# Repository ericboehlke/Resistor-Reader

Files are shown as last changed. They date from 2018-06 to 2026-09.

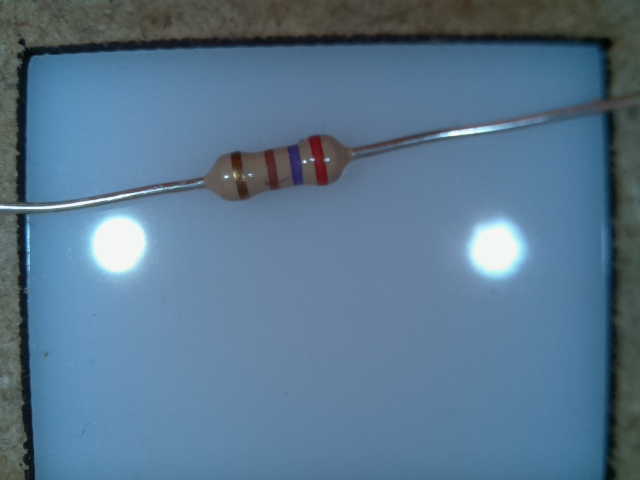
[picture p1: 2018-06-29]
resistor_pictures/0009.jpg

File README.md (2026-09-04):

# Resistor-Reader

Press a button, and a Raspberry Pi Zero photographs the 4-band resistor sitting
on its tray, decodes the colour code with OpenCV, and shows the resistance on a
14-segment display. Fixed LEDs keep the lighting consistent; a failure shows an
error code instead of a wrong answer.

Currently reads **121 of 128** sample images correctly (94.5%). Only tan-bodied
4-band resistors are in scope.

* [docs/ARCHITECTURE.md](docs/ARCHITECTURE.md) — how the pipeline works
* [docs/WORKFLOW.md](docs/WORKFLOW.md) — how to develop and tune it
* [docs/CODE_REVIEW_TODO.md](docs/CODE_REVIEW_TODO.md) — what still needs doing
* [hardware/WIRING.md](hardware/WIRING.md) — enclosure, GPIO wiring, and fasteners

## Development

Uses [uv](https://github.com/astral-sh/uv) for dependencies and
[flit](https://flit.pypa.io) as the build backend. Needs Python 3.11+.

```bash
uv sync            # install
uv run pytest      # run the tests
uvx ruff check .   # lint
uv build           # build a distribution
```

The CV pipeline runs anywhere. `main.py` needs the Pi's hardware (GPIO,
picamera2, I2C display), so on a dev machine drive the pipeline directly:

```bash
uv run python -c "
import numpy, PIL.Image
from resistor_reader.orchestrator import read_pipeline, load_config
r = read_pipeline(numpy.asarray(PIL.Image.open('resistor_pictures/0000.jpg')),
                  load_config('config.yaml'))
print(r.resistance, [c.value for c in r.colors])"
```

## Modes

`main.py` has three:

* **read** — the real one. Waits for the button, captures, runs the pipeline,
  displays the resistance or an error code.
* **gather** — prompts for a known resistance, captures, and appends the image
  and its value to the CSV. This built the test set.
* **camera** — captures to a numbered file on each press. Nothing else.

## Install on a Raspberry Pi Zero

`scripts/prep-sd-card.sh` builds the whole image on a fast machine through a
qemu-arm chroot, so the Pi never has to run `apt` or compile anything. It
installs the packages, clones this repo, builds the venv, enables I2C, installs
the systemd unit, and sets up a CDC-NCM USB gadget so the Pi answers at
`10.42.0.1` over the USB cable.

```bash
sudo ./scripts/prep-sd-card.sh          # see the header for env vars
```

Flash the resulting image, boot it, and the reader starts automatically:

```bash
ssh pi@10.42.0.1
systemctl status resistor-reader
journalctl -u resistor-reader -f
```

To run it by hand, stop the service first:

```bash
sudo systemctl stop resistor-reader
cd ~/Resistor-Reader && .venv/bin/python -m resistor_reader.main read
```

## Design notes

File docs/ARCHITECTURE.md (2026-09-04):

# Architecture

How the resistor reader works today. This describes the code as it is; work
still to be done lives in [CODE_REVIEW_TODO.md](CODE_REVIEW_TODO.md).

## The device

A Raspberry Pi Zero with a camera module looks down at a white acrylic tray
under fixed LEDs. Press the button, and it photographs the 4-band resistor on
the tray, decodes the colour code, and shows the resistance on a 14-segment
display. A failure shows an error code instead.

Only tan-bodied 4-band resistors are in scope.

## The pipeline

`orchestrator.read_pipeline(image, config) -> PipelineResult` runs five stages
in order and short-circuits on the first failure.

| Stage | Module | Produces | Fails with |
| --- | --- | --- | --- |
| Preprocess | `preprocess.py` | tray crop, white balanced | `E07` |
| ROI | `roi.py` | resistor body, rotated horizontal, + body mask | `E02` |
| Segmentation | `segment.py` | four band bounding boxes, + body texture | `E03` |
| Classification | `classify.py` | a score per colour per band | `E04` |
| Decode | `decode.py` | resistance, band order, confidence | `E04` |

### Preprocess

Crops to the tray interior (`processing.crop`, default `[64, 36, 480, 598]` for
a 640x480 capture — outside it is the MDF frame) and applies a gray-world white
balance. A frame the crop does not fit fails with `E07` rather than being
silently truncated.

### ROI

Masks the resistor against the white background by hue distance from the
border's median hue, erodes away the thin leads with a distance transform,
keeps the largest connected component, then rotates the body horizontal and
crops it. Returns the crop and the aligned body mask.

Getting the whole resistor into the mask consistently is still the weak point;
the next stage only needs enough of the bands to segment them, but the better
this stage does, the easier that is.

### Segmentation

Builds a one-dimensional "bandness" signal across the body from two cues:

* **colour** — LAB distance of each column from the resistor body colour,
  measured on a central horizontal strip and averaged over only the darkest
  rows, so specular blobs cannot drag it toward white;
* **texture** — the specular spread of each column, which is the only thing
  that makes a metallic gold band stand out from the beige body it is on.

Plain glare sparkles exactly as hard as a metallic band, so the texture cue is
gated on the *chroma of the highlight*: a metallic sparkle stays a saturated
gold, a reflection off the body washes out to near-white. The texture
contribution is capped so a gold band cannot tower over the others and drag the
detection threshold up with it.

Bands are then extracted as runs above a threshold. No single threshold works
for every resistor — a metallic band scores several times higher than a gray
band next to the body — so the code sweeps for a threshold yielding exactly four
runs, and when none does, keeps the runs it found and fills the rest by claiming
the strongest peaks among the leftover columns. Filling never subdivides a run
already found, which is what stops two boxes landing on the same band.

### Classification

Returns a *score for every colour* on every band rather than a hard label.
Alongside the LAB distance to each reference colour it adds a metallic term:
gold and silver carry their identity in their sparkle, which the matte median
that identifies every other colour deliberately throws away. Without that term
a gold band is indistinguishable from brown, which was the single largest
source of wrong readings.

### Decode

`decode_best` searches both band orders and the top few colour candidates per
band, keeps only sequences forming a legal resistor code, and returns the best
scoring one. Choosing the order is not a detail: a resistor is as likely to be
photographed tolerance-band-left as tolerance-band-right, and the colours are
the only cue to which end is which. The rules are published standards, not
anything learned from the sample images:

* the tolerance band is never black, orange, yellow or white (EIA-RS-279);
* the first significant digit is never black — no leading-zero resistors;
* real parts come from the E24 preferred-value series (IEC 60063), applied as a
  bonus rather than a filter so an unusual part still decodes;
* the result must land in a plausible range.

`resolve_value` in the same module is the pure part: four ordered colours in, a
resistance out, no knowledge of which end is which.

It also returns a **confidence** — the winning reading's score margin over the
best alternative *value*. `main.py` refuses a reading below
`decode.min_confidence` with `E06`, because a wrong answer is worse than an
error. The gate lives in `main.py`, not in `read_pipeline`, so the test suite
keeps measuring raw algorithm accuracy rather than accuracy-after-policy.

## Stage contract

Every stage takes an input dataclass (image + config, plus whatever the previous
stage produced) and returns an output dataclass inheriting `StageResult`:

```python
@dataclass(kw_only=True)
class StageResult:
    error: ErrorCodeEnum | None = None   # None means success
    error_msg: str = ""
    debug_overlay: np.ndarray | None = None
    _metadata: dict[str, Any] = field(default_factory=dict)

    @property
    def success(self) -> bool:
        return self.error is None
```

Two rules make this work:

1. **A stage names its own failure.** The orchestrator propagates `error`
   unchanged; it never re-derives a code from a stage's position in the
   pipeline.
2. **`_metadata` is diagnostics only** — timings, thresholds, debug image
   paths. Anything the next stage needs is a real typed field. That is why
   `SegmentationOutput.body_tex` and `ClassificationOutput.scores` are fields
   and not dictionary keys.

## Error codes

`models.ErrorCodeEnum` is the single source of truth. Names are three
characters so they fit the display.

| Code | Meaning | Raised by |
| --- | --- | --- |
| E01 | camera failure | `main.py` |
| E02 | no resistor found | `roi` |
| E03 | too many/few bands found | `segment`, `classify` |
| E04 | invalid band set | `classify`, `decode` |
| E05 | pipeline crashed | `main.py` |
| E06 | low confidence | `main.py` |
| E07 | bad input image | `preprocess` |

## Debug montage

With `runtime.debug.enabled`, the orchestrator stacks a vertical montage of
every stage's view. Stages hand back their overlay in `debug_overlay`, so
building it never reads back a JPEG the same process just wrote.

```text
+-----------------------------+
| Input                       |
+-----------------------------+
| Preprocessed                |
+-----------------------------+
| ROI Cropped                 |
+-----------------------------+
| Segmentation                |  band boxes
+-----------------------------+
| Classification              |  boxes labelled with the arg-max colour
+-----------------------------+
| Final Overlay               |  boxes + decoded colours + ohms, or the error
+-----------------------------+
```

On failure the final overlay shows what was known at that point: the cropped
image with the error if segmentation failed, red boxes if the bands could not
be classified, the error text in place of the ohms value if decoding failed.

## Performance

Target: under 1 s per capture, preferably under 0.33 s.

Measured on an x86 dev box with debug off, median over 20 images: **6.3 ms**
total (ROI 2.5, classification 1.5, segmentation 1.1, preprocess 0.9, decode
0.2). Per-stage timings are recorded in `_metadata["timings_ms"]` on every run,
so the same numbers can be read off the Pi.

**Not yet measured on the Pi Zero** — that is Phase D and the number that
actually matters.

## Accuracy

121/128 sample images (94.5%). Splitting by resistor value with
`RESISTOR_SPLIT` gives 95.3% on the tuning half and 93.8% on the holdout half,
so the thresholds are not badly overfit to the sample set.

The goal is ~95% on resistors that are present and legible, with errors rare and
wrong answers rarer.

## Deployment

`scripts/prep-sd-card.sh` builds the SD card image on a fast machine via a
qemu-arm chroot: installs the packages, clones the repo, builds the venv,
installs `scripts/resistor-reader.service`, and sets up a CDC-NCM USB gadget at
a static 10.42.0.1 so the Pi is reachable over USB.

The reader starts at boot via systemd and restarts on failure. Logs go to the
journal, which Log2Ram keeps in RAM; debug images are off by default and capped
by `runtime.debug.max_files` when enabled, because `logs/` is that same RAM
disk.

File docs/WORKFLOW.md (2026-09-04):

# Development Workflow

## Setup

```bash
uv sync          # dependencies
uv run pytest    # the whole suite
uvx ruff check . # lint (clean; keep it that way)
```

Everything runs on a dev machine except `main.py`, which imports `board`,
`RPi.GPIO` and `picamera2` and only works on the Pi. Exercise the pipeline with
`orchestrator.read_pipeline` or the test suite instead.

## The regression suite

`test_resistors` in `tests/test_orchestrator.py` runs every photo in
`resistor_pictures/` against the known values in `resistor_pictures/resistors.csv`
(gathered with `main.py gather`). It is the source of truth for accuracy — 121
of 128 as of this writing.

Each run writes `logs/<timestamp>/test_failures.md`: a table of every failure
with the stage that failed, the error, the decoded colours, and a path to the
most useful debug image. Images that pass are run once with debug off; only
failures are re-run with debug on, so a clean run stays fast and does not fill
`logs/`.

The report is one file per run, not a running log across runs — use git if you
want history.

### Honest accuracy numbers

The thresholds were tuned against these photos, so a pass rate over all of them
flatters itself. `RESISTOR_SPLIT` cuts the set in half **by resistor value**
(every value was photographed twice, so splitting by filename would leak one
photo of a pair into the other half):

```bash
RESISTOR_SPLIT=tune    uv run pytest    # tune against this half
RESISTOR_SPLIT=holdout uv run pytest    # then read the honest number here
```

Unset runs everything. Currently 95.3% tune / 93.8% holdout.

## Interactive tuning

`scripts/live_trackbar.py` reruns the whole pipeline on one image as you drag
sliders, showing the debug montage live. It calls the same `read_pipeline` the
appliance does, so what you tune is what runs.

```bash
uv run python scripts/live_trackbar.py \
  --image resistor_pictures/0044.jpg --debug --save-config tuned.yaml
```

Keys: `s` saves the current values to `--save-config`, `r` resets to the file's
values, `q` or Escape quits.

The sliders are integers, so `seg_max_w` and `seg_tex_w` carry their real value
scaled by 100. Adding a slider means adding a row to `TRACKBARS` and, for a
fractional parameter, to `_PERCENT_TRACKBARS`.

## Configuration

One file, `config.yaml`, holds every tunable, and it is what the appliance runs.
Tests load it and force the debug switches in code — there is deliberately no
second copy of the tunables under `tests/`, because a second copy only drifts.

Debug is **off** by default: `logs/` on the appliance is a Log2Ram RAM disk, and
each enabled stage writes a JPEG per button press. `runtime.debug.max_files`
caps the directory when it is on.

Note that stage defaults currently live in two places — `config.yaml` and the
`_*_cfg()` fallbacks in each stage — so a key typo silently falls back to the
code default. See [CODE_REVIEW_TODO.md](CODE_REVIEW_TODO.md).

## Conventions

* Every stage takes an input dataclass and returns an output dataclass; see the
  stage contract in [ARCHITECTURE.md](ARCHITECTURE.md).
* A stage names its own failure with an `ErrorCodeEnum`. Do not add a code
  without adding it to the table in ARCHITECTURE.md.
* `_metadata` is for diagnostics. If the next stage needs it, it is a field.
* Performance matters: the target is under a third of a second on a Pi Zero.
  Vectorize with NumPy/OpenCV; no Python loops over pixels, no ML frameworks.

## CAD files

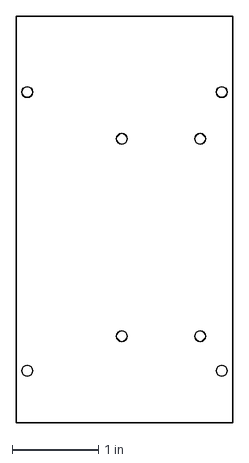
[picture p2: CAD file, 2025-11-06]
hardware/dxfs/back.dxf
2.50 x 4.70 in

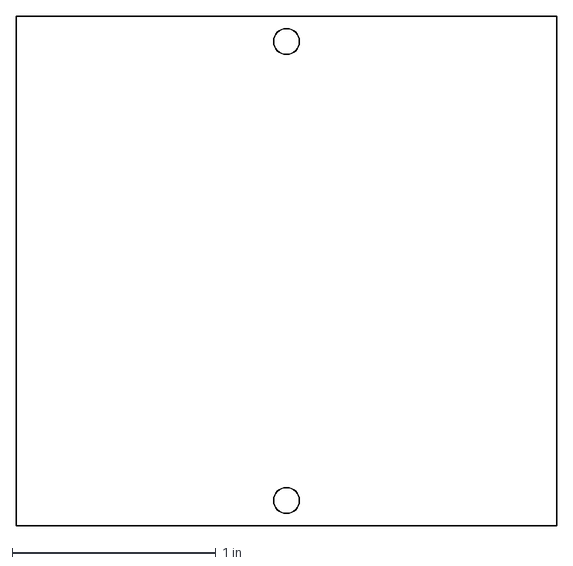
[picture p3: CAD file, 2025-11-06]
hardware/dxfs/bottom.dxf
2.65 x 2.50 in

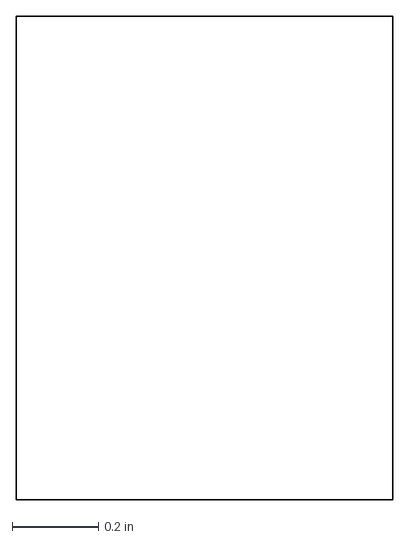
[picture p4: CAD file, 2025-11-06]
hardware/dxfs/background.dxf
0.875 x 1.12 in

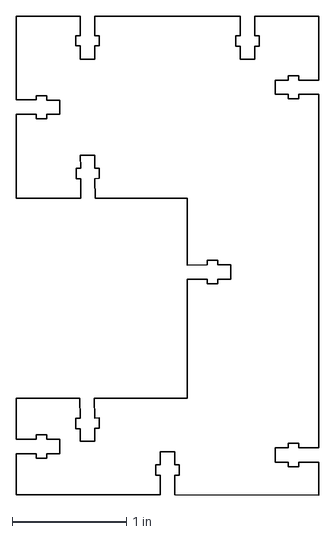
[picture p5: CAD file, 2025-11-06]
hardware/dxfs/right_side.dxf
2.65 x 4.20 in

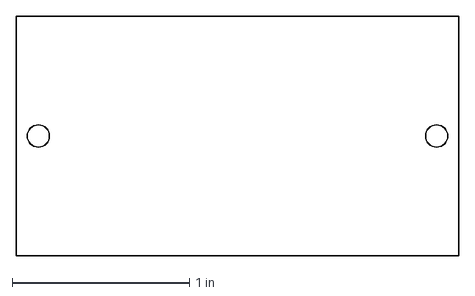
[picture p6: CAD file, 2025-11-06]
hardware/dxfs/bottom_front.dxf
2.50 x 1.35 in

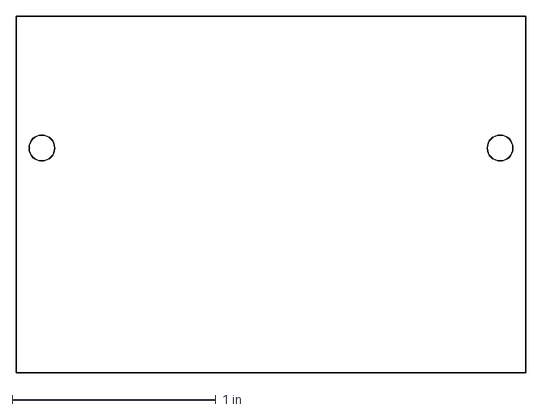
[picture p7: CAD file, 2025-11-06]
hardware/dxfs/backstop.dxf
2.50 x 1.75 in

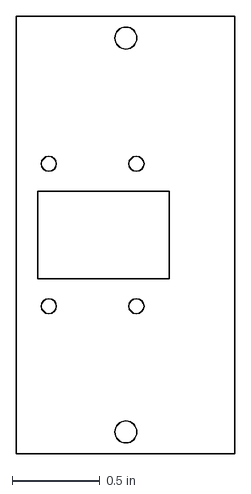
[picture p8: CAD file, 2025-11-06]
hardware/dxfs/camera_mount.dxf
1.25 x 2.50 in

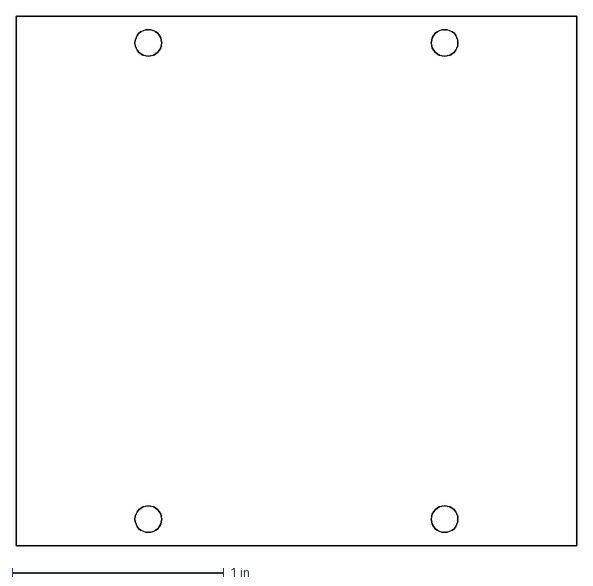
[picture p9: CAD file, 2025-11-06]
hardware/dxfs/top.dxf
2.65 x 2.50 in

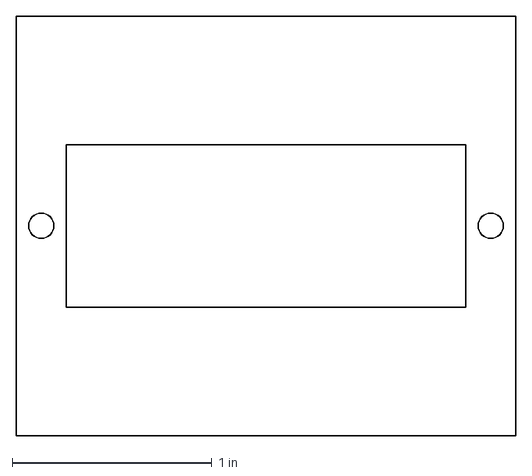
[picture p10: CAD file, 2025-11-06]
hardware/dxfs/top_front.dxf
2.50 x 2.10 in

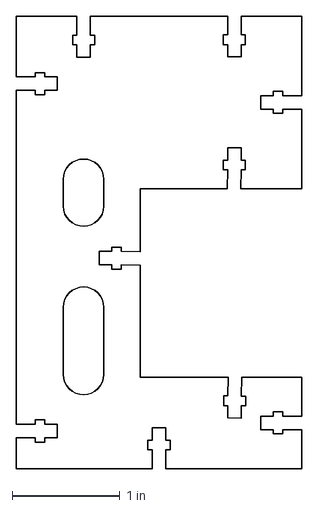
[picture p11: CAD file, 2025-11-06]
hardware/dxfs/left_side.dxf
2.65 x 4.20 in

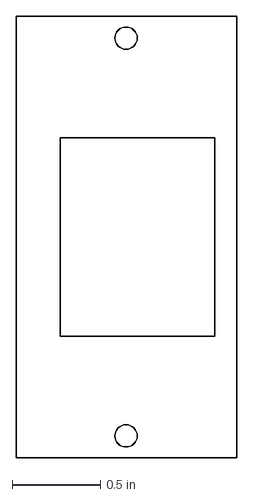
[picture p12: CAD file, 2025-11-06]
hardware/dxfs/bed.dxf
1.25 x 2.50 in

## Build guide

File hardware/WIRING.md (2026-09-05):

# Wiring & mechanical hardware

The enclosure, GPIO wiring, and fasteners for the Pi Zero appliance. This
describes the physical unit; see [docs/ARCHITECTURE.md](../docs/ARCHITECTURE.md)
for the software.

## Parts list

### Mechanical (enclosure)

MDF panels, cut from the DXFs in [`dxfs/`](dxfs): `back`, `background`,
`backstop`, `bed`, `bottom`, `bottom_front`, `camera_mount`, `left_side`,
`right_side`, `top`, `top_front`. Panel stock is nominal 1/4 in (6 mm) MDF.

| Part | Spec | Qty |
| --- | --- | --- |
| Panel-to-panel screw | M3 x 16 mm button head cap screw | 20 | 
| Panel-to-panel nuts | M3 nuts | 20 | 
| Pi standoff | M2.5 x 12 mm nylon standoff, female-female | 4 | 
| Pi standoff screw | M2.5 x 8 mm nylon screw | 8 | 
| Camera mount screw | M2 x 14 mm button head cap screw | 4 | 
| Camera mount nuts | M2 nuts | 4 | 

### Electronic

| Part | Spec |
| --- | --- |
| SBC | Raspberry Pi Zero |
| Camera | Pi Camera Module, `ov5647` sensor, CSI ribbon |
| Display | [Adafruit HT16K33 backpack, 4-digit 14-segment](https://www.adafruit.com/product/1911) |
| Button | Momentary pushbutton — see [Button wiring](#button-wiring) |
| Tray LEDs | 2x white LEDs — see [LED driver](#led-driver) |
| LED resistors | 2x 100Ω, 1/4W, one per LED branch |
| LED driver transistor | 2N2222 NPN, low-side switch: emitter to ground, collector to the LED branches' common return |
| LED base resistor | 1kΩ |
| Reverse-polarity protection | P-channel MOSFET, high-side reverse-polarity stage on the incoming 5V |
| Bulk capacitance | ~2200µF low-ESR electrolytic + 100nF ceramic, on the 5V rail near the Pi's power pin |
| DC-input-sense divider | 10kΩ / 15kΩ resistor divider, tapped off the raw incoming 5V (before reverse-polarity protection) into a spare GPIO |
| Power input jack | 5.5x2.1mm panel-mount DC barrel jack, center-positive — mounts in a hole in the case's back panel |
| Board power connector | 1x2 right-angle male header (board side) + matching Dupont female housing (harness side) — see [Connectors](#connectors)|
| LED connector | 1x4 right-angle male header (board side) + matching Dupont female housing (harness side) — see [Connectors](#connectors) |
| Display connector | 1x5 right-angle male header (board side) + matching Dupont female housing (harness side) — see [Connectors](#connectors) |
| Button connector | 1x2 right-angle male header (board side) + matching Dupont female housing (harness side) — see [Connectors](#connectors) |

## Power input

Power comes in over a panel-mount DC barrel jack, 5V only — no USB-C, no
negotiation of any kind, no buck/boost stage, since the input is already at
the 5V the Pi and LEDs want. This is deliberately the simplest option: a
barrel jack is just two conductors (center + shield), with no connector-side
electronics or breakout board to select and mate.

- **Connector:** a 5.5x2.1mm panel-mount DC barrel jack, center-positive
  (the near-universal convention for 5V wall adapters), mounted in a hole in
  the case's back panel. Two wires run from it to a 2-pin header on the
  board.
- **Current headroom:** unlike USB-C, there's no negotiation step at all —
  whatever the wall adapter is rated for is what's available, no resistor
  values or connector logic involved. **Minimum recommended supply: 5V/2A**,
  given the worst-case simultaneous load of camera capture + both LEDs +
  display digits lit at once.
- **Reverse-polarity protection:** a P-channel MOSFET stage rather than a
  series diode — a diode's ~0.3-0.4V drop would eat too far into the Pi's
  already-thin under-voltage margin on a bare 5V-in design with no
  regulator stage to make it up. This matters more than it would with
  USB-C: a barrel jack has no keying or polarity enforcement at all, and
  center-negative 5V adapters do exist, so a miswired or wrong adapter is a
  real (not just theoretical) risk here.
- **Bulk capacitance** on the 5V rail near the Pi's power pin does two
  jobs, which is why it's sized above a "just for ripple" value:
  1. Smooths the short (sub-second) current spike from camera + LEDs +
     display all drawing at once — the moment a reading is actually taken.
  2. Bridges the Pi through a clean shutdown once power loss is detected
     (see [Soft shutdown](#soft-shutdown-on-power-loss) below) for a few
     hundred ms under typical debugging-session load. This is explicitly
     **not** sized to survive a worst-case fully-loaded unplug — a
     guarantee like that would need a supercap + boost UPS stage, which
     was considered and deliberately skipped in favor of this simpler cap.
  Final value should be checked against measured peak current once built,
  not just typical datasheet numbers.
- The protected, buffered 5V feeds the Pi's 5V pin directly (powered via
  the GPIO header rather than the Pi's own micro-USB port) and the LED
  driver branch.
- If `vcgencmd get_throttled` or dmesg under-voltage warnings show up
  during real-load testing anyway, the next step is a shorter/thicker
  cable/wire run or an added boost stage — not built in preemptively.

### Soft shutdown on power loss

To reduce the risk of SD card corruption if the barrel jack is unplugged —
most relevant when the root filesystem's read-only protection is turned off
for debugging — a spare GPIO senses the raw incoming 5V (before the
reverse-polarity stage) through the 10kΩ/15kΩ divider above. That raw input
collapses essentially instantly on unplug, well before the downstream bulk
capacitor sags, so the Pi gets an early edge to react to while it's still
running on stored charge. A small watcher (same gpiozero pattern already
used for the button in `resistor_reader/main.py`) should trigger a clean
`shutdown -h now` on that falling edge. **This watcher script/systemd unit
is a software follow-up, not delivered as part of this hardware plan** —
see the checklist below.

## GPIO pinout

The Pi's 40-pin header is 20 rows of 2 pins, running away from the SD card
slot. "Row *N*" below counts rows from the SD-card end (row 1 = pins 1/2).
Within a row, **inside** = the odd-numbered pin, **outside** = the
even-numbered pin.

| Row (from SD card) | Inside pin | Outside pin | Function |
| --- | --- | --- | --- |
| 1 | Pin 1 — **3.3V** | Pin 2 — **5V** | Inside: display VCC/Vi2c + button. Outside: 5V rail (LED driver supply + Pi power) |
| 2 | Pin 3 — **GPIO2 (SDA1)** | Pin 4 — 5V | Inside: display SDA |
| 3 | Pin 5 — **GPIO3 (SCL1)** | Pin 6 — **GND** | Inside: display SCL. Outside: ground return |
| 6 | Pin 11 — **GPIO17** | Pin 12 — GPIO18 (unused) | Button signal, active-high, internal pull-down — see [Button wiring](#button-wiring) |
| 7 | Pin 13 — **GPIO27** | Pin 14 — GND | LED driver control, via transistor base resistor |
| 8 | Pin 15 — **GPIO22** | Pin 16 — GND (unused) | DC-input-sense input for soft shutdown — new, not yet read by any software |

Matches `main.py`'s existing defaults (`button_pin=17`, `leds_pin=27`,
`resistor_reader/main.py:305-306`) and I2C1 defaults (`board.I2C()` in
`setup_display()`). GPIO22 is newly assigned for VBUS sensing and isn't
referenced by any code yet.

## Button wiring

The button sits between 3.3V and `GPIO17`, with no separate ground leg.
`setup_gpio()` in `main.py` configures `Button(pin, pull_up=False, ...)`,
which enables GPIO17's internal pull-down: the pin idles LOW and reads HIGH
when the button ties it to 3.3V on a press. This is the deliberate design —
it needs no external pull resistor and no code changes.

## LED driver

The two tray LEDs are white, which puts their forward voltage
around 3.0-3.2V @ 20mA typical — too high for two in series on a 5V rail
(that would need ~6.0-6.4V combined). They're wired as **two parallel
branches**, each with its own 100Ω resistor, sharing a single 2N2222
low-side switch:

- Rail: 5V. Transistor: `Vce(sat)` ≈ 0.2V.
- Per branch: `Vresistor = 5V − Vf − Vce(sat) ≈ 5 − 3.0..3.2 − 0.2 ≈ 1.6-1.8V`
- `I = Vresistor / 100Ω ≈ 16-18mA` per LED — safely under a typical 20mA
  max, with the resistor dissipating ~30mW (well under a 1/4W part's rating).
- Each LED gets its **own** resistor rather than sharing one across both
  parallel LEDs, so a slight Vf mismatch between the two doesn't cause one
  LED to hog current from the other.
- Both resistors live **on the main board**; only the bare LEDs are remote
  (out in the tray). Each LED's anode (post-resistor) and cathode return
  are carried as two independent conductors over the 1x4 harness — see
  [Connectors](#connectors) — with the two cathode returns joining at the
  transistor's collector back on the board.
- Base: `GPIO27` through a 1kΩ resistor, `Ib ≈ 2.6mA`. Total collector
  current for both branches is ~34mA, far below what a 2N2222 needs to
  saturate (min hFE ~100 implies saturation well under 3.4mA of base
  current) — deep saturation is guaranteed with plenty of margin.
- The LED pin is driven purely on/off in software (`LED`, not `PWMLED`, in
  `resistor_reader/main.py`) — no PWM dimming to account for in the driver
  design.

## Circuit

```mermaid
graph LR
    subgraph PWR["Power input"]
        JACK["5.5x2.1mm barrel jack (panel mount)"]
        SENSE["10k/15k divider"]
        PROT["P-MOSFET reverse-polarity protection"]
        CAP["Bulk cap: 2200uF + 100nF"]
    end

    subgraph Pi["Pi Zero 40-pin header"]
        P1["Pin 1 — 3.3V"]
        P2["Pin 2 — 5V"]
        P3["Pin 3 — GPIO2 SDA1"]
        P5["Pin 5 — GPIO3 SCL1"]
        P6["Pin 6 — GND"]
        P11["Pin 11 — GPIO17"]
        P13["Pin 13 — GPIO27"]
        P15["Pin 15 — GPIO22"]
    end

    JACK -->|raw 5V| SENSE
    SENSE -->|sensed level| P15
    JACK -->|raw 5V| PROT
    PROT --> CAP
    CAP --> P2

    P1 --> DCONN["1x5 right-angle header"]
    P3 -->|SDA| DCONN
    P5 -->|SCL| DCONN
    P6 --> GND["Ground bus"]
    DCONN --> DISP["Display: VCC, Vi2c, GND, SDA, SCL"]

    P1 --> BCONN["1x2 right-angle header"]
    P11 ---|GPIO17, internal pull-down| BCONN
    BCONN --> BTN["Button (not illuminated)"]

    P13 --> BASE["1k ohm base resistor"]
    CAP --> Q1["2N2222 (collector)"]
    BASE --> Q1
    GND -->|emitter| Q1
    Q1 --> R1["100 ohm"] --> LCONN["1x4 right-angle header"]
    Q1 --> R2["100 ohm"] --> LCONN
    LCONN --> LED1["LED 1"] --> GND
    LCONN --> LED2["LED 2"] --> GND

    style DCONN fill:#3b82f6,color:#fff
    style CAP fill:#ef4444,color:#fff
    style GND fill:#111,color:#fff
    style BASE fill:#eab308,color:#000
    style PROT fill:#eab308,color:#000
```

## Connectors

Board-side headers are **right-angle**, not straight — the case's internal
clearance doesn't have room for a straight header plus a Dupont housing
stacked on top. Each mates with a Dupont female housing crimped onto the
corresponding harness.

| Connector | Pin 1 | Pin 2 | Pin 3 | Pin 4 | Pin 5 |
| --- | --- | --- | --- | --- | --- |
| LED (1x4) | LED1 anode (post-R1) | LED1 cathode return | LED2 anode (post-R2) | LED2 cathode return | — |
| Display (1x5) | VCC (3.3V) | Vi2c (3.3V, bridged to VCC on-board) | GND | SDA | SCL |
| Button (1x2) | 3.3V | GPIO17 | — | — | — |
| Power (1x2) | 5V | GND | — | — | — |

## Build checklist

Items to confirm as the build comes together:

1. **Confirm actual LED `Vf`** once the LEDs are in hand (measure or check
   the datasheet) — the 100Ω resistor value above assumes 3.0-3.2V; recompute
   if the real part differs meaningfully.
2. **Breadboard-test the power section** (barrel jack → reverse protection
   → bulk cap → Pi) before committing it to the enclosure.
3. **Check for under-voltage warnings** (`vcgencmd get_throttled`, dmesg)
   under real combined load — camera capture + LEDs + display active at
   once — with the actual wall adapter you intend to use.
4. **Confirm the barrel jack's panel-mount hardware fits** the case's back
   panel thickness, and double-check the wall adapter you use is
   center-positive before plugging it in.
   confirm they seat properly once the 5 mm standoffs are actually swapped in.
5. **Write the soft-shutdown watcher** (spare GPIO22 read via gpiozero,
   triggering a clean `shutdown -h now` on DC input loss) as a follow-up
   software task — not part of this hardware plan.
6. **Confirm the right-angle headers' mounted orientation clears the case**
   once the board is in hand — check that the LED (1x4), display (1x5), and
   button (1x2) Dupont housings can actually be seated with the board in
   its final mounted position.

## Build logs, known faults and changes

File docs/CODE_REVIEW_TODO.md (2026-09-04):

# Open work

What is left after the September 2026 cleanup. The review that produced this
list is in the git history; everything below is still open.

Current state: **121/128** sample images (94.5%; 95.3% tune / 93.8% holdout),
**6.3 ms** per image on an x86 dev box, `ruff check .` clean, 52 tests passing
plus `test_resistors` failing at the 7 images below.

---

## The seven failures

Ranked by how wrong they are. `logs/<run>/test_failures.md` links a debug
montage for each after any test run.

| Image | Expected | Read as | Confidence | Note |
| --- | --- | --- | --- | --- |
| 0110 | 1 M | 88 | 8.10 | worst miss; confident and wrong |
| 0067 | 22 k | 1.2 k | 0.22 | caught by the E06 gate |
| 0064 | 33 k | 43 k | 0.53 | caught by the E06 gate |
| 0044 | 3.9 k | 390 | 5.42 | multiplier band misread |
| 0127 | 2.2 | 220 | 3.95 | multiplier band misread |
| 0123 | 5.1 | 510 | 4.32 | multiplier band misread |
| 0126 | 5.1 | 5.0 | 3.33 | brown/black on the second digit |

- [ ] Four of the seven are **multiplier-band errors off by exactly 100x**
      (0044, 0127, 0123), or a gold/black multiplier confusion (0126). That is
      a pattern, not seven separate bugs — a metallic-vs-dark multiplier is the
      thing to look at first.
- [ ] 0110 is the only high-confidence miss and the only one the E06 gate
      cannot catch. Worth understanding on its own.

## Accuracy and calibration

- [ ] Take **50 more photos** with `main.py gather`. The current 128 are the
      set every threshold was tuned against; the holdout split says the tuning
      generalizes, but 64 held-out images is a thin basis for a 95% claim.
- [ ] Re-derive `decode.min_confidence` once there is more data. It is 1.0 now,
      measured on 128 images where only three fall below it — a threshold set
      from three data points.

## Pi Zero (Phase D)

- [ ] **Measure the pipeline on the actual Pi Zero.** Nothing here has ever
      been timed on target hardware. The budget is 1 s, ideally 0.33 s;
      per-stage timings are already recorded in `_metadata["timings_ms"]`, so
      this is a matter of reading them off a real run.
- [ ] Confirm the systemd unit works end to end on a fresh image: does it start
      on boot, does the button work, does the display come up, does it recover
      after a crash.

## Architecture

- [ ] **Stage defaults live in two places.** Every tunable is declared in
      `config.yaml` *and* in the `_*_cfg()` fallback in its stage, and a third
      time as the default column in `live_trackbar.TRACKBARS`. A typo'd YAML
      key silently falls back to the code default with no warning. Replace the
      `dict` config with typed dataclasses (`SegmentationConfig`,
      `ClassificationConfig`, `DecodeConfig`, `RuntimeConfig`) loaded once by
      `load_config`, rejecting unknown keys, and generate the trackbar list
      from their fields.
- [ ] `SegmentationOutput.bounding_boxes` always spans the full crop height
      (`(x0, 0, x1, h)`), so two of the four coordinates carry no information.
      Either make them mean something or make the type a column range.
- [ ] `main.py` uses bare `print()`. That works — the systemd unit sends stdout
      to the journal — but a real logger would let the appliance run quieter
      than the tuning session. Low priority.
- [ ] `tests/_best_debug_path` has three near-identical branches that differ
      only in ordering. Collapse.

## Deployment (Phase E)

- [ ] `docs/STEPS.md` planned a **pi-gen fork**. `scripts/prep-sd-card.sh`
      solved the same problem differently — staging a Raspbian Lite image on a
      loop device through a qemu-arm chroot — and is what actually works today.
      Decision: no pi-gen fork; delete the idea rather than carry it. Recorded
      here because the plan is otherwise only in the deleted file's history.
- [ ] Verify Log2Ram is actually configured on the built image. The debug-image
      cap and the journal both assume it.

---

## Done in this pass

For anyone reading the diff: unified the error code space (E01-E07, one owner
per code) and made stages report their own typed error; promoted `body_tex` and
the classifier `scores` matrix from the debug-only `_metadata` dict to real
fields; merged `resolve.py` into `decode.py`; rebuilt the orchestrator around a
run context, removing five copies of the result construction and the round-trip
that re-read stage overlays back off disk as JPEGs; split the 692-line
`bands.py` into `segment.py`/`classify.py`/`imageops.py`; moved the preprocess
crop and every ROI constant into config; made preprocess reject a frame it
cannot crop (E07) instead of silently truncating; turned debug off by default
and capped the debug directory; deleted the duplicate `tests/test.yaml`; wired
up the long-ignored decode confidence as an E06 gate; added
`scripts/resistor-reader.service`; fixed the `live_trackbar` slider that opened
the tool at 1/100th of the configured texture weight; deleted `read_resistor`,
`PipelineInput`, the unrunnable matplotlib plot path, nine unused test fixtures
and four stale documents; and brought `ruff` from 38 findings to zero and the
test count from 18 to 52.

Accuracy was 121/128 before and after — none of it was an algorithm change.

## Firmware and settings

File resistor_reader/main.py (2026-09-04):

"""Appliance entry point: button, camera, pipeline, segment display."""

from __future__ import annotations

import argparse
import csv
import time
import traceback
from dataclasses import dataclass, field
from pathlib import Path
from typing import Any

import board
from adafruit_ht16k33 import segments
from gpiozero import LED, Button
from picamera2 import Picamera2

from resistor_reader import orchestrator
from resistor_reader.display import resistance_str, show_error, show_message
from resistor_reader.models import ErrorCodeEnum


@dataclass
class Config:
    button_pin: int
    leds_pin: int
    resolution: tuple[int, int]
    awb_gains: tuple[float, float]
    save_dir: Path = Path("resistor_pictures")
    csv_path: Path = Path("resistor_pictures/resistors.csv")
    start_number: int = 0
    # Fixed exposure for the (unchanging) tray lighting. ``None`` means measure
    # it once at startup; see ``setup_camera``.
    exposure_time: int | None = None
    analogue_gain: float = 1.0
    # Loaded once at startup rather than re-read from disk on every capture.
    pipeline_config: dict[str, Any] = field(default_factory=dict)
    image_number: int = 0

    @property
    def min_confidence(self) -> float:
        """Score margin below which a reading is refused as ``E06``.

        Zero (the default) accepts every reading the decoder considers legal.
        """
        decode_cfg = self.pipeline_config.get("decode", {}) or {}
        return float(decode_cfg.get("min_confidence", 0.0))


def ensure_paths(config: Config):
    config.save_dir.mkdir(parents=True, exist_ok=True)
    if not config.csv_path.exists():
        with open(config.csv_path, "a", newline="") as f:
            writer = csv.writer(
                f, delimiter=",", quotechar="|", quoting=csv.QUOTE_MINIMAL
            )
            writer.writerow(["number", "resistance"])


def setup_gpio(config: Config) -> tuple[Button, LED]:
    # The switch ties the GPIO pin to 3.3V (not GND) when pressed -- see
    # hardware/WIRING.md -- so pull_up=False: gpiozero enables the internal
    # pull-down and reports the button pressed when the pin reads HIGH.
    # gpiozero picks the lgpio backend on this Pi (RPi.GPIO's edge detection
    # is broken on its kernel -- see wait_for_press's old docstring in git
    # history -- but lgpio talks to the modern gpiochip interface directly,
    # so edge waits work).
    button = Button(config.button_pin, pull_up=False, bounce_time=0.03)
    leds = LED(config.leds_pin)
    return button, leds


def setup_display():
    display = segments.Seg14x4(board.I2C())
    display.brightness = 0.5
    display.fill(0)
    return display


def _converge_exposure(
    cam, *, min_frames: int = 4, max_frames: int = 40, tol: float = 0.03
):
    """Step through frames until auto-exposure settles, and return the
    ``(ExposureTime microseconds, AnalogueGain)`` to lock in.

    With the LEDs on and steady, the AEC/AGC parks within a couple of frames
    and stays put; the hunting only happens when it meters a dark frame after
    the LEDs switch off between reads, which is exactly what locking prevents.
    ``capture_metadata`` blocks for the next frame, so the loop advances one
    frame per iteration.
    """
    prev = None
    exposure = gain = None
    for i in range(max_frames):
        metadata = cam.capture_metadata()
        exposure = metadata.get("ExposureTime")
        gain = metadata.get("AnalogueGain")
        if exposure is None or gain is None:
            break
        if i + 1 >= min_frames and prev and abs(exposure - prev) <= tol * prev:
            break
        prev = exposure
    if not exposure or not gain:
        raise RuntimeError("camera gave no exposure metadata to calibrate from")
    return int(exposure), float(gain)


def setup_camera(config: Config, leds: LED):
    cam = Picamera2()
    config_obj = cam.create_still_configuration(main={"size": config.resolution})
    cam.configure(config_obj)
    cam.start()

    # Manual white balance: the tray lighting is fixed, so a hunting AWB only
    # adds colour drift between reads.
    cam.set_controls({"AwbEnable": False, "ColourGains": config.awb_gains})

    # Lock exposure too. Left on auto, the AGC hunts to its ceiling after the
    # first frame and blows every later capture out -- red reads as orange,
    # brown as gold, or the resistor is lost against the background. The
    # lighting never changes, so one measurement under the LEDs holds for the
    # whole session.
    if config.exposure_time is not None:
        exposure, gain = config.exposure_time, config.analogue_gain
    else:
        leds.on()
        try:
            exposure, gain = _converge_exposure(cam)
        finally:
            leds.off()
        print(f"Calibrated exposure: {exposure} us at gain {gain:.2f}")
    cam.set_controls(
        {"AeEnable": False, "ExposureTime": exposure, "AnalogueGain": gain}
    )
    return cam


def gather_mode(picam2, display, config: Config, button: Button, leds: LED):
    """Gather mode:
    Prompt for resistance, take picture, save image and resistance in CSV.
    """
    show_message(display, "GATH")
    ensure_paths(config)
    resistance = input("resistance: ").strip()
    try:
        float(resistance)
    except ValueError:
        print("Invalid resistance value, please enter a number.")
        return
    show_message(display, resistance_str(float(resistance)))
    filename = config.save_dir / f"{str(config.image_number).zfill(4)}.jpg"
    leds.on()
    time.sleep(0.1)
    picam2.capture_file(str(filename))
    time.sleep(0.1)
    leds.off()
    with open(config.csv_path, "a", newline="") as csvfile:
        writer = csv.writer(
            csvfile, delimiter=",", quotechar="|", quoting=csv.QUOTE_MINIMAL
        )
        writer.writerow([str(config.image_number), resistance])
    print(f"Saved image {filename} with resistance {resistance}")
    config.image_number += 1


def camera_mode(picam2, display, config: Config, button: Button, leds: LED):
    """Camera mode:
    Wait for button press, take picture, save with incrementing filename.
    """
    while (outfile := Path(f"camera_capture_{config.image_number}.jpg")).exists():
        config.image_number += 1
    show_message(display, "PUSH")
    print("Ready: press the button to take a picture...")
    button.wait_for_press()
    print("Taking picture with flash...")
    show_message(display, "SNAP")
    leds.on()
    time.sleep(0.1)
    picam2.capture_file(str(outfile))
    time.sleep(0.1)
    leds.off()
    show_message(display, "DONE")
    print(f"Saved to {outfile.resolve()}")
    # Wait for release so we don't immediately retrigger
    button.wait_for_release()


def read_mode(picam2, display, config: Config, button: Button, leds: LED):
    """Read mode:
    Wait for button press, take a picture, run the pipeline, and show the
    resistance -- or the failing stage's error code -- on the display.
    """
    button.wait_for_press()
    print("Taking picture...")
    show_message(display, "READ")
    leds.on()
    time.sleep(0.1)
    try:
        img_array = picam2.capture_array("main")
    except Exception as e:  # camera not ready, driver/I-O error
        leds.off()
        show_error(display, ErrorCodeEnum.E01, str(e))
        time.sleep(2)
        button.wait_for_release()
        return
    time.sleep(0.1)
    leds.off()

    print("Processing image...")
    try:
        result = orchestrator.read_pipeline(img_array, config.pipeline_config)
    except Exception:  # a stage blew up instead of reporting failure
        traceback.print_exc()
        show_error(display, ErrorCodeEnum.E05, "pipeline crashed")
        time.sleep(2)
        button.wait_for_release()
        return

    if result.failure is not None or result.resistance is None:
        show_error(display, result.failure or ErrorCodeEnum.E04, result.error_msg)
        time.sleep(2)
        button.wait_for_release()
        return

    # A wrong reading is worse than no reading, so refuse a value the
    # decoder could not separate from its runner-up.
    if not orchestrator.is_confident(result, config.min_confidence):
        show_error(
            display,
            ErrorCodeEnum.E06,
            f"margin {result.confidence:.1f} < {config.min_confidence:.1f}",
        )
        time.sleep(2)
        button.wait_for_release()
        return

    colors = ", ".join(c.value for c in result.colors) if result.colors else "?"
    timings = result._metadata.get("timings_ms", {})
    total_ms = sum(timings.values())
    print(
        f"Detected resistance: {result.resistance:g} ohms [{colors}] "
        f"in {total_ms:.0f} ms (confidence {result.confidence:.1f})"
    )
    show_message(display, resistance_str(result.resistance))
    # Wait for release so we don't immediately retrigger
    button.wait_for_release()


def run_loop(mode_func, config: Config):
    config.image_number = config.start_number
    display = None
    picam2 = None
    button = None
    leds = None
    try:
        display = setup_display()
        show_message(display, "LOAD")
        button, leds = setup_gpio(config)
        try:
            picam2 = setup_camera(config, leds)
        except Exception as e:  # no camera attached, driver failure
            print(f"Camera initialization failed: {e}")
            show_error(display, ErrorCodeEnum.E01, str(e))
            time.sleep(3)
            raise
        while True:
            mode_func(picam2, display, config, button, leds)
    except KeyboardInterrupt:
        pass
    finally:
        if picam2 is not None:
            try:
                picam2.stop()
                picam2.close()
            except Exception:
                pass
        if button is not None:
            button.close()
        if leds is not None:
            leds.close()
        if display is not None:
            try:
                display.fill(0)
            except Exception:
                pass


def parse_resolution(text: str) -> tuple[int, int]:
    if "x" not in text.lower():
        raise ValueError("Resolution must be in the format WxH, e.g. 640x480")
    w, h = text.lower().split("x", 1)
    return int(w), int(h)


def parse_awb_gains(text: str) -> tuple[float, float]:
    if "," not in text:
        raise ValueError("AWB gains must be in the format red,blue, e.g. 1.5,1.4")
    r, b = text.split(",", 1)
    return float(r), float(b)


def build_parser() -> argparse.ArgumentParser:
    parser = argparse.ArgumentParser(description="Resistor Reader")
    subparsers = parser.add_subparsers(dest="mode", required=True, help="Operation mode")

    def add_common_args(sp):
        sp.add_argument("--button-pin", type=int, default=17, help="GPIO pin for button")
        sp.add_argument("--leds-pin", type=int, default=27, help="GPIO pin for LEDs")
        sp.add_argument(
            "--resolution",
            type=str,
            default="640x480",
            help="Camera resolution, e.g. 640x480",
        )
        sp.add_argument(
            "--awb-gains", type=str, default="1.5,1.4", help='AWB gains as "red,blue"'
        )
        sp.add_argument(
            "--exposure-time",
            type=int,
            default=None,
            help="Lock exposure to N microseconds (default: measure it at startup)",
        )
        sp.add_argument(
            "--analogue-gain",
            type=float,
            default=1.0,
            help="Analogue gain to pair with --exposure-time",
        )

    parser_gather = subparsers.add_parser("gather", help="Gather mode")
    add_common_args(parser_gather)
    parser_gather.set_defaults(func=gather_mode)
    parser_gather.add_argument(
        "--csv-path",
        type=str,
        default=None,
        help="Path to CSV file (default: <save-dir>/resistors.csv)",
    )
    parser_gather.add_argument(
        "--save-dir",
        type=str,
        default="resistor_pictures",
        help="Directory to save images and CSV",
    )
    parser_gather.add_argument(
        "--start-number", type=int, default=0, help="Starting image number"
    )

    parser_camera = subparsers.add_parser("camera", help="Camera mode")
    add_common_args(parser_camera)
    parser_camera.set_defaults(func=camera_mode)
    parser_camera.add_argument(
        "--start-number", type=int, default=0, help="Starting image number"
    )

    parser_read = subparsers.add_parser("read", help="Read mode")
    add_common_args(parser_read)
    parser_read.set_defaults(func=read_mode)
    parser_read.add_argument(
        "--pipeline-config-file",
        type=str,
        default="config.yaml",
        help="Config file for the image processing pipeline.",
    )
    return parser


def config_from_args(args: argparse.Namespace) -> Config:
    save_dir = Path(getattr(args, "save_dir", "resistor_pictures"))
    csv_path = getattr(args, "csv_path", None)
    return Config(
        button_pin=args.button_pin,
        leds_pin=args.leds_pin,
        resolution=parse_resolution(args.resolution),
        awb_gains=parse_awb_gains(args.awb_gains),
        save_dir=save_dir,
        csv_path=Path(csv_path) if csv_path else save_dir / "resistors.csv",
        start_number=getattr(args, "start_number", 0),
        exposure_time=args.exposure_time,
        analogue_gain=args.analogue_gain,
        pipeline_config=orchestrator.load_config(
            getattr(args, "pipeline_config_file", None)
        ),
    )


def main():
    args = build_parser().parse_args()
    run_loop(args.func, config_from_args(args))


if __name__ == "__main__":
    main()

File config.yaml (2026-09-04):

# Pipeline tuning: only keys read by `resistor_reader` stages are kept here.
#
# This is the appliance config, so debug is OFF -- `logs/` is a Log2Ram RAM disk
# and every enabled stage writes a JPEG per button press. Turn `runtime.debug`
# on for tuning (`scripts/live_trackbar.py --debug`); the test suite enables it
# per failing image on its own.

processing:
  # Tray interior of the 640x480 capture: top, left, bottom, right. Everything
  # outside is the MDF frame. A frame the crop does not fit fails with E07
  # rather than being silently truncated.
  crop: [64, 36, 480, 598]
  debug_image: true

region_of_interest:
  # Foreground test against the white acrylic: hue far enough from the
  # background's, saturated enough, and darker than the background.
  hue_diff_min: 8
  sat_min: 40
  value_max: 220
  open_kernel: 5
  dilate_kernel: 10
  close_kernel: 5
  # Leads are thinner than this many pixels and get eroded away.
  lead_distance: 15.0
  crop_pad: 8
  debug_image: true

segmentation:
  # Column profile is built from a central horizontal strip so the shaded,
  # curved top and bottom of the body do not wash the band colours out.
  strip_top: 0.28
  strip_bottom: 0.74
  matte_keep_ratio: 0.70
  band_smooth_window: 7
  # Metallic bands are found by their specular sparkle.  The chroma gate tells
  # that sparkle apart from plain glare on the body, which washes out to near
  # white; the cap stops a gold band from towering over the others and dragging
  # the detection threshold up with it.
  texture_weight: 1.0
  texture_cap: 25.0
  highlight_ratio: 0.15
  chroma_gate_low: 70.0
  chroma_gate_high: 110.0
  # Band extraction: sweep for a threshold giving exactly four runs, then fill
  # any bands the sweep missed by claiming the strongest leftover peaks.
  thr_frac_min: 0.20
  thr_frac_max: 0.75
  thr_frac_step: 0.025
  min_signal: 5.0
  min_band_width_px: 5
  min_band_separation_px: 9
  max_band_width_ratio: 0.35
  peak_extent_frac: 0.45
  peak_rise_tol: 0.15
  edge_margin: 4
  end_pin_ratio: 0.04
  upsample: 4
  debug_image: true

classification:
  strip_top: 0.25
  strip_bottom: 0.75
  matte_keep_ratio: 0.70
  # Gold and silver are scored by specular spread rather than mean colour: the
  # matte median that identifies every other colour throws their sheen away.
  metallic_gain: 26.0
  metallic_offset: 34.0
  metallic_scale: 22.0
  metallic_min_value: 70.0
  metallic_max_hue: 28.0
  silver_max_sat: 70.0
  highlight_ratio: 0.15
  chroma_gate_low: 70.0
  chroma_gate_high: 110.0
  debug_image: true

decode:
  # Search the top-k colours per band across both band orders, keeping only
  # sequences that form a legal resistor code.
  top_k: 3
  gold_tolerance_bonus: 10.0
  e24_bonus: 8.0
  min_resistance: 0.1
  max_resistance: 1.0e8
  # Refuse a reading (E06) whose score margin over the next-best *value* is
  # below this, because a wrong reading is worse than an error.
  #
  # Measured over the 128 sample images: correct readings have a median margin
  # of 11.0 (min 0.50), wrong ones a median of 3.95 (min 0.22). The
  # distributions overlap badly, so this only cuts the very bottom -- at 1.0 it
  # rejects two of the seven wrong readings and one correct one, leaving three
  # images below the line in total. Raising it to 3.0 would cost three correct
  # readings to catch the same two errors, which is the wrong trade.
  min_confidence: 1.0

runtime:
  debug:
    enabled: false
    dir: "logs/"
    # Oldest images are dropped past this count; 0 disables pruning.
    max_files: 200

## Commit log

2018-06-29 Starting images, and tests
    [resistors.csv]
2025-08-12 Parametrize tests for resistor images
2025-08-13 Crop out resistor body from leads
2025-11-06 Add dxf files
    [back.dxf, background.dxf, backstop.dxf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]
2026-04-13 Add glare-resistant classification and consolidate resistor tests
    - Classify bands using percentile brightness filter and median RGB (highlight_keep_percentile)
    - Document pipeline config in WORKFLOW; align .cursorrules with test_resistors as source of truth
    - Remove redundant unit tests; add pass/fail summary to test failure report
    [bands.py, config.yaml]
2026-09-03 Refactor band detection and improve accuracy to 93%
    - Enhance band segmentation with improved peak detection and
    body-mask-aware logic
    - Add decode module for robust band color recognition
    - Refine glare-resistant classification for better real-world
    performance
    - Update orchestrator to use optimized detection pipeline
    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
2026-09-03 Add SD card prep script for headless Pi Zero appliance
    prep-sd-card.sh stages a freshly-flashed Raspberry Pi OS (32-bit Trixie
    Lite) card from a fast host via a qemu-arm chroot, so the slow work
    (apt full-upgrade, package install, pip builds) doesn't run on the Pi's
    single core.
    It configures default creds + SSH, USB OTG gadget ethernet
    (ssh pi@10.42.0.1 over the data port, NM ipv4 method=shared), installs
    the README apt packages, clones this repo at the claude-rewrite branch,
    builds the venv with adafruit-circuitpython-ht16k33, enables i2c, and
    disables debug JPEG writes in config.yaml. Read-only overlayfs is left
    as a one-time on-Pi command to avoid building an initramfs under qemu.
    Co-A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
2026-09-03 Rework prep-sd-card.sh to stage an image file on a loop device
    Point the qemu-arm staging at a Raspberry Pi OS Lite .img[.xz] on a loop
    device on the laptop's disk instead of a physically-mounted microSD card,
    so every dpkg write lands on NVMe. The script no longer flashes; it
    produces a staged WORK_IMG and prints the dd command.
    - IMG= accepts .img or .img.xz; a .xz source is decompressed once to a
    reusable work copy, the original is never touched. IMG_SIZE (default
    6G) grows the work image for the apt/pip work; first boot on the real
    card auto-expands the rootfs.
    - loop device via losetup -P, grow partition 2 + resize2fs, mount, do
    the existing boot/NM/chroot staging,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
2026-09-03 prep-sd-card: unmount udisks2 automounts before detaching loop device
    The desktop's udisks2 auto-mounts the loop device's partitions in the file
    manager as soon as `losetup -P` creates them. Those mounts kept the device
    open, so cleanup()'s `losetup -d` could only flag it for autoclear and the
    loopN entry lingered in lsblk across runs (with stale, sometimes deleted,
    backing files). cleanup() now unmounts any outside mount of our partitions
    before detaching. Adds findmnt to the preflight tool check.
    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
2026-09-04 roi/preprocess: replace scipy hotspots with OpenCV, ~3x faster pipeline
    The front of the pipeline was dominated by scipy routines operating on the
    full frame. On a Pi Zero this made each read painfully slow.
    - _remove_leads: scipy.ndimage.distance_transform_edt -> cv2.distanceTransform
    (DIST_MASK_PRECISE); ~13x faster, bit-identical threshold result.
    - _largest_component: scipy.ndimage.label + ndimage.sum ->
    cv2.connectedComponentsWithStats (4-connectivity to match); ~7x faster.
    - _rotate_and_crop: was warping the whole frame twice (INTER_CUBIC image +
    INTER_NEAREST mask) only to read a bounding box off the rotated mask. Now
    transform the foreground points through the rotation matri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
    [preprocess.py, roi.py]
2026-09-04 prep-sd-card: switch USB gadget from g_ether/NM-shared to CDC-NCM + static IP
    The legacy g_ether (CDC-ECM) gadget's bulk TX path stalls against many xHCI
    hosts ("cdc_ether ... NETDEV WATCHDOG: transmit queue timed out"), and the
    NetworkManager method=shared profile depended on the Pi running DHCP/NAT for
    the host.
    - Assemble the gadget at boot as CDC-NCM via configfs/libcomposite
    (usb-gadget-ncm.sh + usb-gadget-ncm.service), ordered before NetworkManager
    so the interface holds a static 10.42.0.1/24.
    - cmdline.txt now loads only dwc2 early; no modules-load=g_ether and no
    g_ether.*_addr params. Fixed gadget MACs move into the NCM function config.
    - Mark the gadget iface unmanaged in Net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
2026-09-04 prep-sd-card: drop python3-scipy from the appliance package list
    resistor_reader no longer imports scipy (replaced with OpenCV in 794321a),
    so the appliance does not need it installed.
    Claude-Session: https://claude.ai/code/session_011mDmhVA1PEi7acySSkAnkr
2026-09-04 orchestrator/test: build debug montage only on demand; instrument failures only
    The montage build (overlay render + two debug-image reads + multi-panel
    composite) and its JPEG write ran on every pipeline call, and the orchestrator
    test forced debug on for all 128 sample images -- ~750 JPEG writes per run,
    dominating wall time on the Pi.
    - orchestrator._finalize_pipeline_result: only render/build/write the montage
    when runtime.debug.enabled is set or an explicit debug_montage_path is
    given. Otherwise PipelineResult.debug_image is None (callers already handle
    that).
    - test_resistors: first pass runs every image with debug off; only images that
    fail are re-run with debug on to populate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
    [orchestrator.py]
2026-09-04 main/read: surface pipeline error codes on the display
    read_mode called the read_resistor convenience wrapper, which collapses
    every failure into a ValueError shown as a generic "Err". Switch it to
    read_pipeline and report the actual code: E01 on a camera capture
    exception, the stage's own E02/E03/E04 on a reported failure, and E02
    with a traceback when a stage raises instead of returning a result.
    Also harden the entrypoint:
    * run_loop's finally block dereferenced picam2/display unconditionally,
    so a setup_camera() failure (no camera attached) raised NameError and
    masked the real error. Guard both on None, and show E01 + re-raise on
    camera init failure so a camera-less boot fails re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
    [main.py]
2026-09-04 Remove dead code: read_resistor, PipelineInput, unused fixtures
    Pure subtraction, no behaviour change (test_resistors holds at 121/128).
    * orchestrator.read_resistor: labelled "backward-compatible" but called from
    nowhere; this project has no backwards-compatibility requirement.
    * models.PipelineInput: never constructed.
    * bands.segment_bands: _extract_bands returns four runs or raises, so the
    `success = len(boxes) == 4` check and its failure branch were unreachable.
    * bands._segmentation_cfg: dropped `create_plot`, which segment_bands read
    straight from the raw config instead, like the other debug switches.
    * live_trackbar: dropped --stage, documented as "reserved" and never read.
    *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
    [bands.py, debug_montage.py, models.py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]
2026-09-04 Unify the stage contract and the error code space
    The display used to show a code whose meaning depended on which module set
    it: main.py reported a pipeline crash as E02 ("no resistor found") and the
    orchestrator reported a preprocess failure as E01 ("camera failure"), while
    stages recorded a *third* opinion in _metadata["error_code"] that nothing read.
    Now there is one code space with one owner per code. Stages return a typed
    `error: ErrorCodeEnum | None` and the orchestrator propagates it unchanged
    instead of re-deriving a code from position in the pipeline. Added E05
    (pipeline crashed), E06 (low confidence) and E07 (bad input image); every name
    is three characters and fits the display, w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
    [bands.py, decode.py, display.py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]
2026-09-04 Make the appliance config safe, and stop duplicating it
    The shipped config had debug on with every stage's debug_image set, so each
    button press wrote five or six JPEGs into logs/ -- a Log2Ram RAM disk with no
    rotation and no cleanup. Debug is off by default now, and save_image prunes the
    oldest images past runtime.debug.max_files (200; 0 disables).
    tests/test.yaml was a byte-identical copy of config.yaml, so every tuning
    change had to be made twice or the tests silently ran against stale values.
    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
2026-09-04 Split bands.py, drop the broken plot path, fix packaging
    bands.py was 692 lines doing four jobs. Now:
    segment.py (372) band segmentation
    classify.py (183) colour scoring
    imageops.py (54) strip_bounds/matte_mean/annotate_bands, shared by both
    Deleted the matplotlib segmentation plot and its `create_plot` switch. It
    could not run: matplotlib is not a declared dependency and is not installed,
    so `create_plot: true` raised ModuleNotFoundError. Reviving it would mean
    putting matplotlib on a Pi Zero to draw something the debug montage and
    live_trackbar already cover, so it goes rather than gets fixed.
    Packaging:
    * requires-python 3.8 -> 3.11. The code has needed >=3.10 for a while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
    [classify.py, config.yaml, debug_montage.py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]
2026-09-04 Gate low-confidence readings, and add the systemd unit
    decode has always computed a confidence -- the winning reading's score margin
    over the best alternative *value* -- and nothing ever read it. ARCHITECTURE.md
    says a wrong answer is worse than an error, so read mode now refuses a thin
    margin with E06.
    The threshold is measured, not guessed. Over the 128 sample images:
    correct (n=121): min 0.50 p25 8.59 median 11.04 max 22.55
    wrong (n=7): min 0.22 p25 0.53 median 3.95 max 8.10
    The distributions overlap badly, so the gate only cuts the very bottom. At 1.0
    it rejects two of the seven wrong readings (0067: 22k read as 1.2k; 0064: 33k
    read as 43k) and one correct one (0038,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
    [config.yaml, main.py, orchestrator.py]
2026-09-04 Rewrite the docs to describe the program that exists
    docs/ described at least three different versions of this project. The worst
    offender was AGENTS.md, which defined a parallel E01-E08 error scheme that
    contradicted ErrorCodeEnum, documented config keys that never existed
    (camera:, display:, runtime.timeout_ms, processing.work_width), and stubbed
    modules that were never written (acquisition.py, export.py, errors.py). An
    agent following it would have written the wrong program.
    Deleted outright:
    * .cursorrules -- its useful rules fold into AGENTS.md; the rest was stale.
    * docs/COLOR_SPEC.md, docs/READING_RESISTORS.md -- verbatim copies of
    classify.COLOR_RGB and decode's DIGIT_MAP/MULTIPLI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
    [classify.py, image_log.py, orchestrator.py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]
2026-09-04 main: lock camera exposure, and set up the button pin
    Auto-exposure was left on (only AWB was disabled). The AGC meters the dark
    frame after the LEDs switch off between reads, ramps toward its ceiling, and
    the next lit capture comes back blown out -- red decodes as orange, brown as
    gold, or the resistor is lost against the background entirely. Only the very
    first capture after a cold camera start read correctly.
    Measure the exposure once under the LEDs at startup and lock it (AeEnable
    off, fixed ExposureTime/AnalogueGain); the tray lighting never changes, so
    one calibration holds for the session. With it steady the AGC parks in a
    couple of frames. --exposure-time / --analogue-gain override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
    [main.py]
2026-09-04 main: switch button/LED handling from RPi.GPIO to gpiozero
    RPi.GPIO's wait_for_edge relies on the legacy /sys/class/gpio export
    interface, which no longer works against this kernel's GPIO controller
    (the write to export fails outright) -- only plain register-mapped
    GPIO.input/output still work. gpiozero picks the lgpio backend here,
    which talks to the modern gpiochip interface directly, so
    Button.wait_for_press()/wait_for_release() work again and the manual
    debounce-and-recheck dance is no longer needed (gpiozero's bounce_time
    does it).
    Claude-Session: https://claude.ai/code/session_01X6QdArMK217ocmi6ErndPA
    [main.py]
2026-09-04 main: route all display writes through the crash-safe show_message wrapper
    gather_mode/camera_mode and two status writes in read_mode/run_loop called
    display.print() directly, bypassing the show_message() helper that already
    exists to swallow I2C write failures. On this unit the display's I2C
    connection is intermittently flaky, so a dropped write during `gather` took
    the whole process down with an uncaught OSError.
    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
    [main.py]
2026-09-04 docs: document enclosure fasteners and GPIO wiring
    Adds hardware/WIRING.md: parts list (fastener sizes normalized to
    standard metric stock), the GPIO pinout for the button/LEDs/display,
    and a circuit diagram, reconstructed from a physical inspection of the
    unit and cross-checked against the pin defaults in main.py.
    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
2026-09-04 main: fix button pull direction to match its 3.3V wiring
    The button ties GPIO17 to 3.3V (not GND) when pressed -- confirmed
    while documenting the wiring in hardware/WIRING.md. pull_up=True had
    gpiozero expecting the opposite polarity (pin shorted to GND), so a
    press produced no edge for wait_for_press()/wait_for_release() to see.
    pull_up=False matches the actual wiring with no rewiring needed.
    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
    [main.py]
2026-09-05 docs: write plan for new wiring
    Update WIRING.md to include making a custom PCB to house the circuit
    with pin headers and dupont connectors connecting the other components
    to the hat PCB. Include large capacitors and an auto shutdown mechanism
    as well.
